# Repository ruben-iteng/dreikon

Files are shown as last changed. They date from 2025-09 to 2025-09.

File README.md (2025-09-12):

<div align="center">

# DREIKON

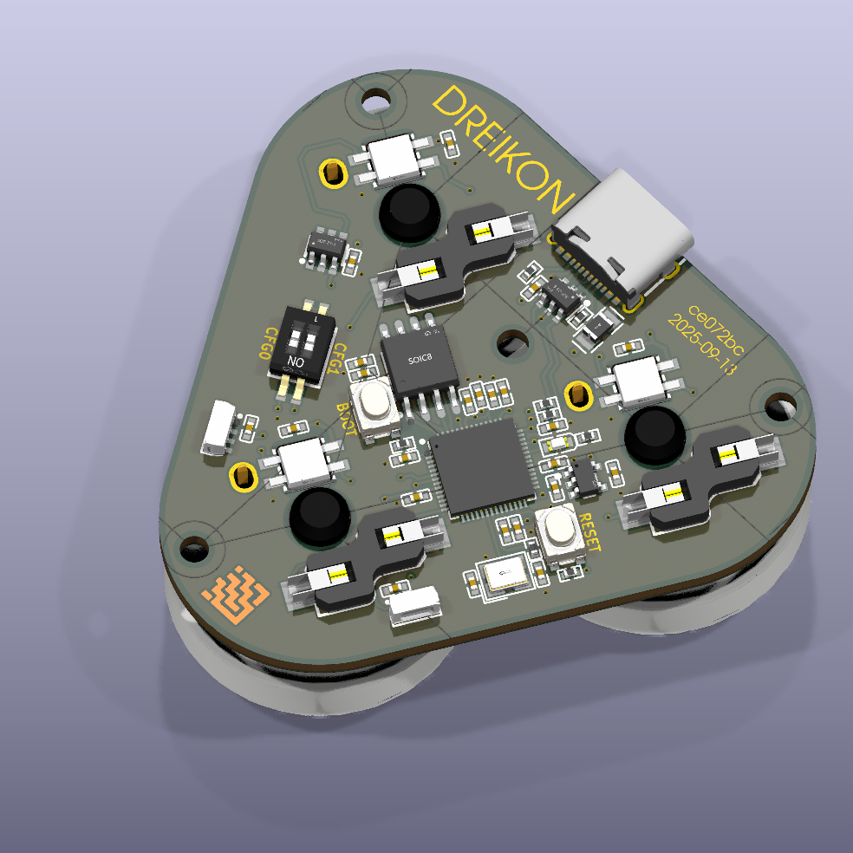
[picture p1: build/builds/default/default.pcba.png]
DREIKON PCBA Top bottom

</div>

## About

A triple button mechanical keyboard for all your macro needs.

## Features

- 3x hotswap sockets for Kailh low profile switches (CHOC v2)
- 3x RGB addressable LEDs for switch underglow
- 2x RGB addressable LEDs for front color bar
- USB Type-C
- 2x DIP switches for configuration
- RP2040 microcontroller

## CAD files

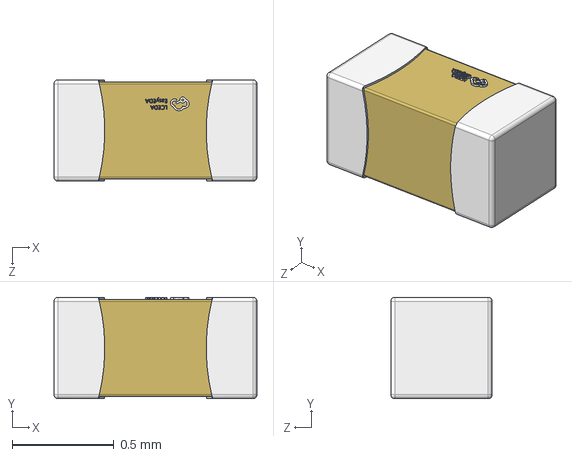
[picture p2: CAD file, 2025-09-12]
parts/FH_0402CG150J500NT/C0402_L1.0-W0.5-H0.5.step
1.00 x 0.5 x 0.5 mm

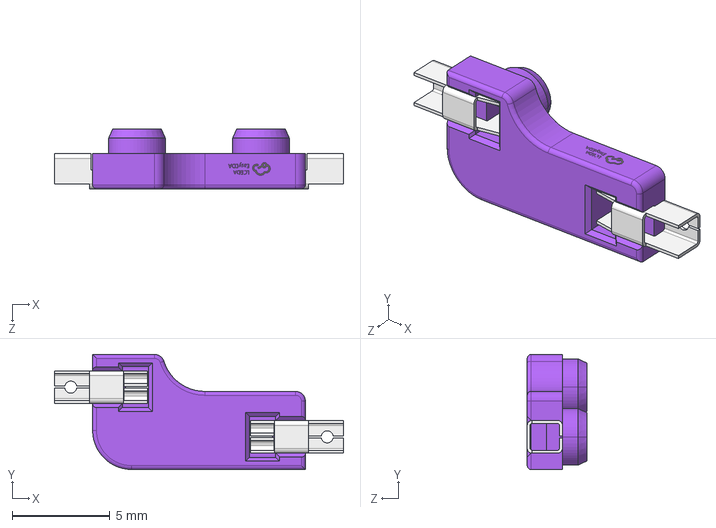
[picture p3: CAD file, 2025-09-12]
parts/HanElectricity_CPG151101S11_16/2.STEP
14.8 x 5.89 x 3.05 mm

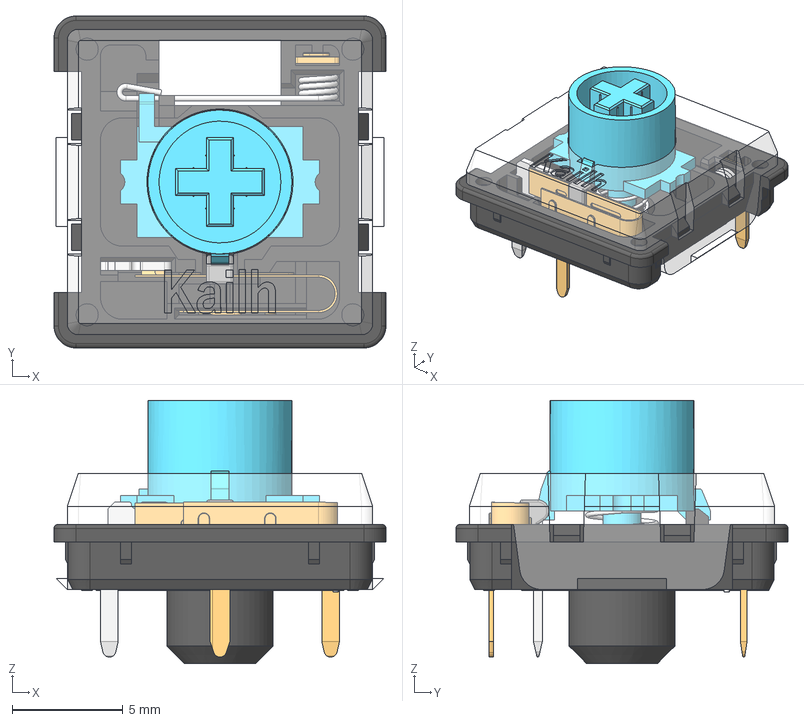
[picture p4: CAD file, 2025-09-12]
parts/KAILH_CPG135001S30/blue.step
15.0 x 15.0 x 11.9 mm
bottom
contact
pin1
stem
top
pin2
pin3
click_bar
shrunken_spring

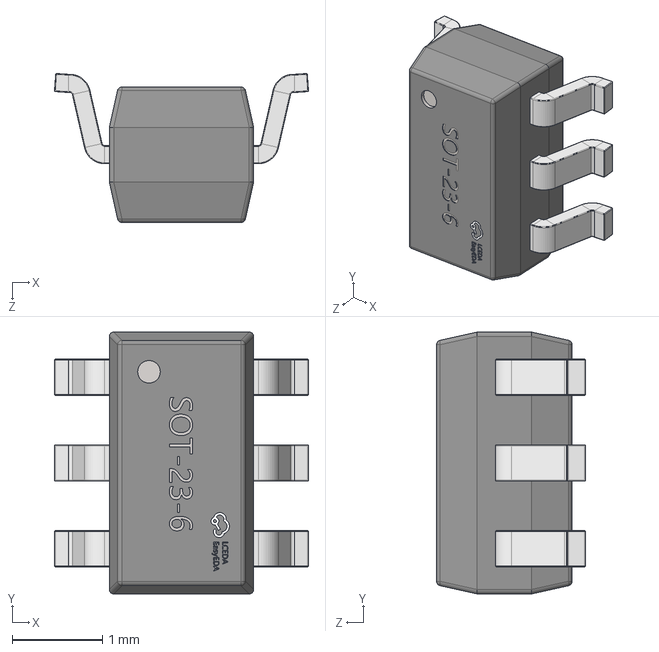
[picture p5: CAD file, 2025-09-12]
parts/UMW_SN74LVC2G34DBVR_UMW/SOT-23-6_L2.9-W1.6-H1.5-LS2.8-P0.95.step
2.81 x 2.90 x 1.65 mm

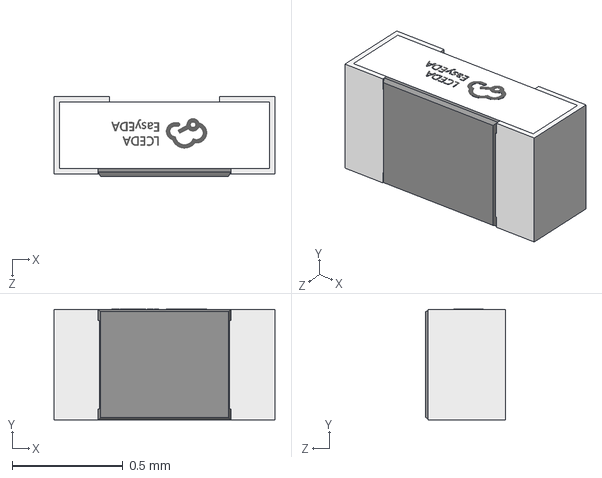
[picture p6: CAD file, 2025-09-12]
parts/UNI_ROYAL_0402WGF1001TCE/R0402_L1.0-W0.5-H0.4.step
1.00 x 0.501 x 0.36 mm

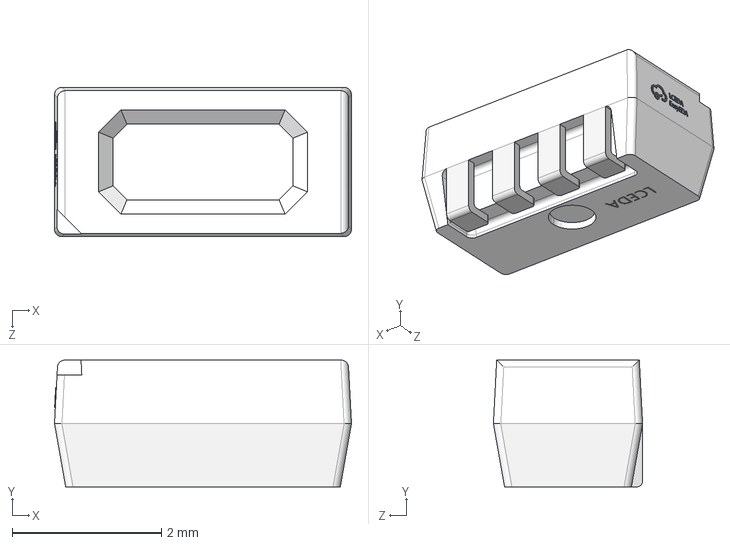
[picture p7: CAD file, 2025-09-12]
parts/Worldsemi_WS2812B_4020/LED-SMD_WS2812B-4020.step
3.98 x 1.70 x 2.00 mm

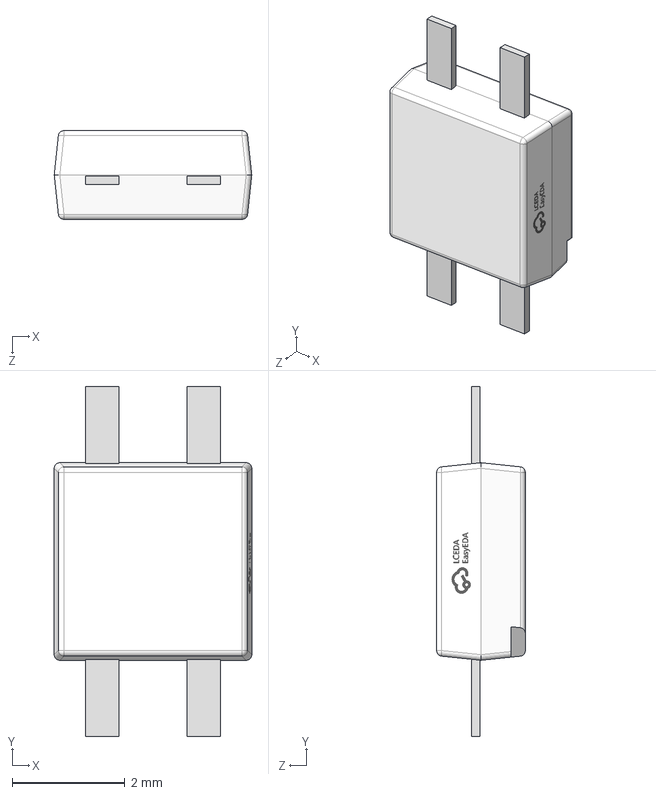
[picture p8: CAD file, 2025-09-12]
parts/Worldsemi_WS2812B_MINI_V3J/LED-SMD_4P-L3.5-W3.5-P1.80-LS6.2_WS2812B-MINI-V3J.STEP
3.50 x 6.20 x 1.57 mm

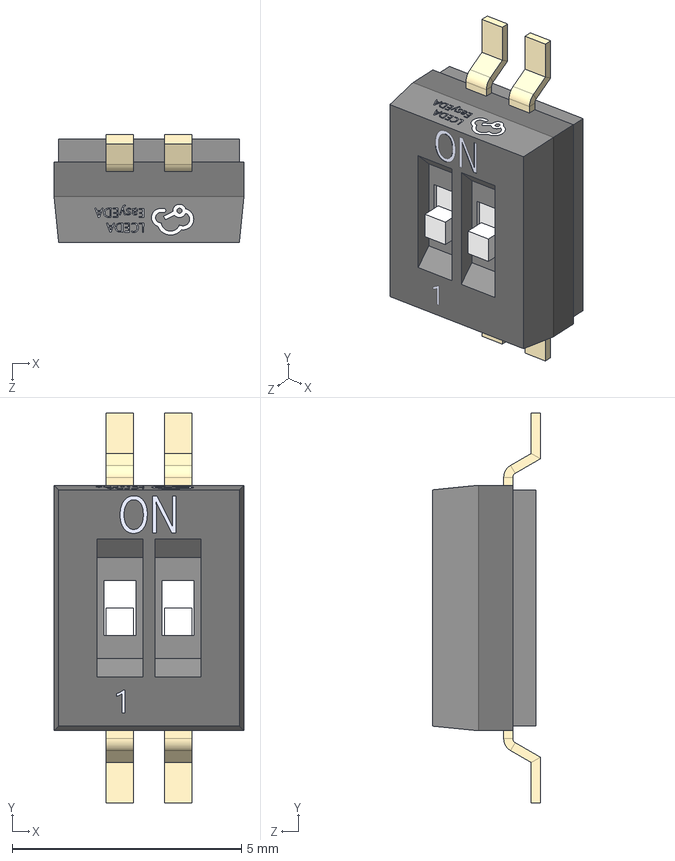
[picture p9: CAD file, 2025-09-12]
parts/XKB_Connectivity_DSHP02TS_S/SW-SMD_DSHP02TS-S-L4.1-W5.4-H2.4-P1.27-LS8.5.step
4.14 x 8.50 x 2.35 mm

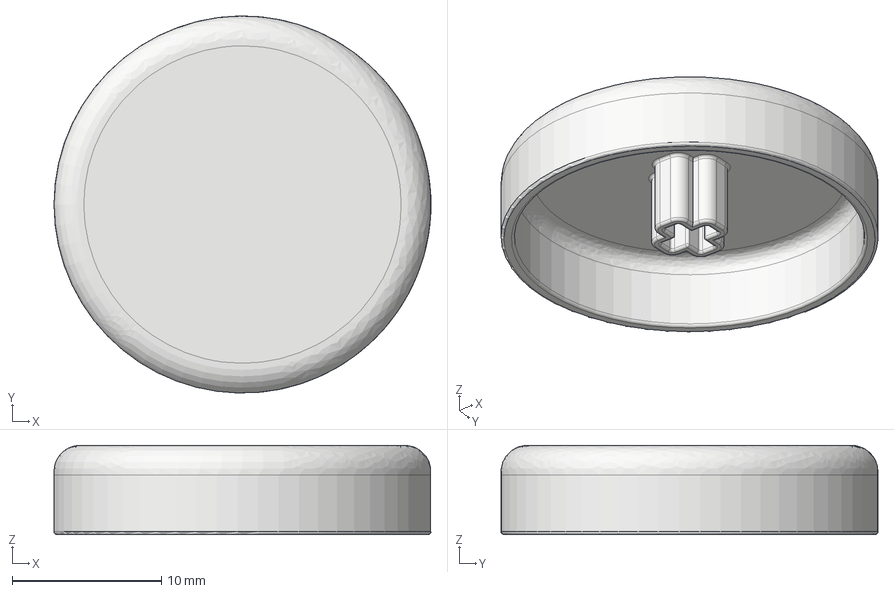
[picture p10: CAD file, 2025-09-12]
parts/KAILH_CPG135001S30/arcade_button_cap.step
25.3 x 25.3 x 6.00 mm

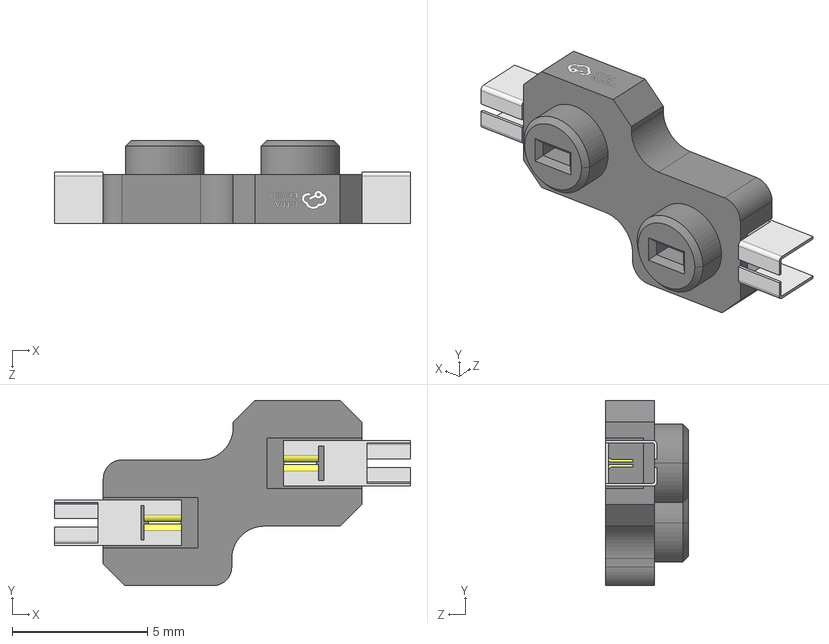
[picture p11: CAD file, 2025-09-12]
parts/KAILH_CPG135001S30/CONN-SMD_HOTPLUGPAKAGE__C9900010116.STEP
13.2 x 6.85 x 3.05 mm

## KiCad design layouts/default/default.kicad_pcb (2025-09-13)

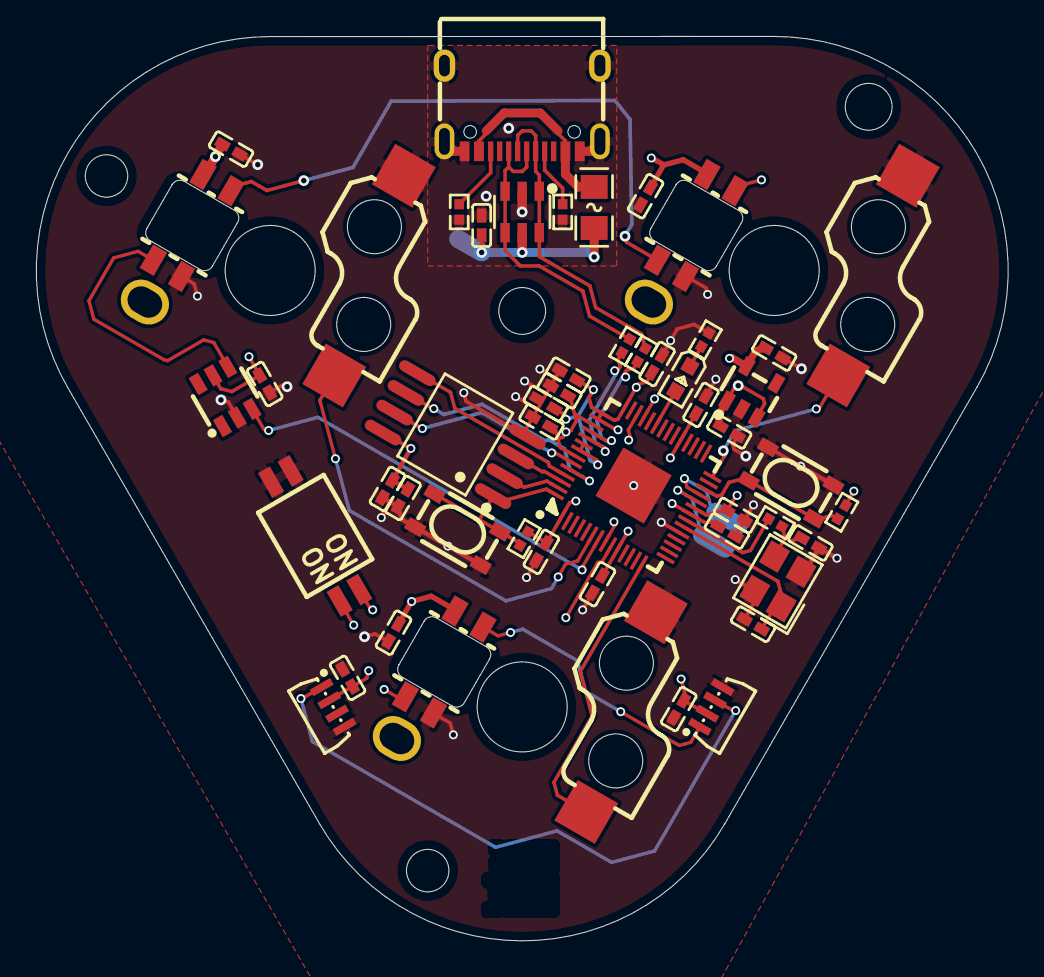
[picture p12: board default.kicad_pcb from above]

Board: 4 copper layers, 54.0 x 50.2 mm, 52 parts (0 on the bottom side), 34 nets.

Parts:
C1, C2, C3, C5, C6, C10, C11, C12, C13, C14, C15, C17, C18, C19, C20, C21, C22, C23: 100nF ±10% 16V X7R; C0402
C4, C9, C16: 2.2µF ±20% 6.3V X5R; C0402
C7, C8: 15pF ±5% 50V C0G; C0402
D1: SOT-23-6_L2.9-W1.6-P0.95-LS2.8-BL
F1: F0805
LED1, LED2, LED3: LED-SMD_4P-L3.5-W3.5-P1.80-LS6.2_WS2812B-MINI-V3J
LED4: LED0603-RD
LED5, LED6: LED-SMD_WS2812B-4020
LOGO1: atopile_Logo_4x4mm
R1, R3, R4: 10kΩ ±1% 62.5mW; R0402
R2: 1kΩ ±1% 62.5mW; R0402
R5, R6: 27Ω ±1% 62.5mW; R0402
R7, R8: 5.1kΩ ±1% 62.5mW; R0402
SW1, SW2: KEY-SMD_4P-L4.2-W3.2-P2.20-LS4.6
SW3: SW-SMD_DSHP02TS-S
U1, U2, U3: CONN-SMD_HOTPLUGPAKAGE__C9900010116
U4: CRYSTAL-SMD_4P-L3.2-W2.5-BL
U5: LQFN-56_L7.0-W7.0-P0.4-EP
U6: SOIC-8_L5.3-W5.3-P1.27-LS8.0-BL
U7: SOT-23-5_L2.9-W1.6-P0.95-LS2.8-BR
U8: SOT-23-6_L2.9-W1.6-P0.95-LS2.8-BR
USB1: USB-C-SMD_TYPE-C-6PIN-2MD-073

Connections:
A: LED4.2, U5.37
GND: C1.2, C2.2, C3.2, C4.2, C5.2, C6.2, C7.2, C8.2, C9.2, C10.2, C11.2, C12.2, C13.2, C14.2, C15.2, C16.2, C17.2, C18.2, C19.2, C20.2, C21.2, C22.2, C23.2, D1.2, LED1.3, LED2.3, LED3.3, LED5.4, LED6.4, R3.1, R7.2, R8.2, SW1.3, SW1.4, SW2.3, SW2.4, SW3.3, SW3.4, U1.2, U2.2, U3.2, U4.2, U4.4, U5.19, U5.57, U6.4, U7.2, U8.2, USB1.1, USB1.12, USB1.13, USB1.14, USB1.15, USB1.16
K: LED4.1, R3.2
RUN: R4.1, SW2.1, SW2.2, U5.26
XIN: C7.1, U4.1, U5.20
XOUT: R2.2, U5.21
_core_regulator_out_power-VCC: C4.1, C5.1, C6.1, U5.23, U5.45, U5.50
cc[0]-line: R7.1, USB1.4
cc[1]-line: R8.1, USB1.10
chip_select: R1.1, SW1.1, SW1.2, U5.56, U6.1
clock: U5.52, U6.6
data_0: U5.53, U6.5
data_1: U5.55, U6.2
data_2: U5.54, U6.3
data_3: U5.51, U6.7
data_in-DIN: LED5.3, LED6.1
gpio[5]-line: U5.7, U8.3
gpio[6]-line: SW3.2, U5.8
gpio[7]-line: SW3.1, U5.9
input-USB_D_N: D1.1, D1.6, R6.1, USB1.5, USB1.7
input-USB_D_P: D1.3, D1.4, R5.1, USB1.6, USB1.8
led_data_out-DIN: LED3.2, LED5.1
led_power-VCC: C1.1, C2.1, C3.1, C18.1, C20.1, C21.1, C22.1, C23.1, D1.5, F1.2, LED1.1, LED2.1, LED3.1, LED5.2, LED6.2, U7.1, U7.3, U8.5
output: C8.1, R2.1, U4.3
output-USB_D_N: R6.2, U5.46
output-USB_D_P: R5.2, U5.47
power-VCC: C9.1, C10.1, C11.1, C12.1, C13.1, C14.1, C15.1, C16.1, C17.1, C19.1, R1.2, R4.2, U5.1, U5.10, U5.22, U5.33, U5.42, U5.43, U5.44, U5.48, U5.49, U6.8, U7.5
power_vbus-VCC: F1.1, USB1.2, USB1.11
switches[0]-led_data_in-line: LED1.4, U8.4
switches[0]-output-contact[0]: U1.1, U5.6
switches[1]-led_data_in-line: LED1.2, LED2.4
switches[1]-output-contact[0]: U2.1, U5.28
switches[2]-led_data_in-line: LED2.2, LED3.4
switches[2]-output-contact[0]: U3.1, U5.14

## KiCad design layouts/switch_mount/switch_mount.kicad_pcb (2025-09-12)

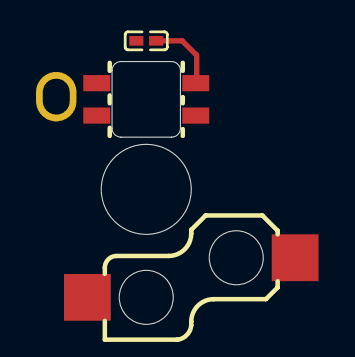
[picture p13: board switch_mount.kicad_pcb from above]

Board: 2 copper layers, 3 parts (0 on the bottom side), 2 nets.

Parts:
C1: 100nF ±10% 16V X7R; C0402
LED1: LED-SMD_4P-L3.5-W3.5-P1.80-LS6.2_WS2812B-MINI-V3J
U2: CONN-SMD_HOTPLUGPAKAGE__C9900010116

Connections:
VCC: C1.1, LED1.1
power-GND: C1.2, LED1.3

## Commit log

2025-09-06 Add pull-up resistor to esp32-c3 boot pin
2025-09-12 Initial design and project files
    [2.STEP, C0402_L1.0-W0.5-H0.5.step, CONN-SMD_HOTPLUGPAKAGE__C9900010116.STEP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]
2025-09-12 Add sub licence and build clean
    [default.kicad_pcb]
2025-09-13 feat(PCB): Finish routing
    [default.kicad_pcb]
2025-09-13 Add 3D board render
